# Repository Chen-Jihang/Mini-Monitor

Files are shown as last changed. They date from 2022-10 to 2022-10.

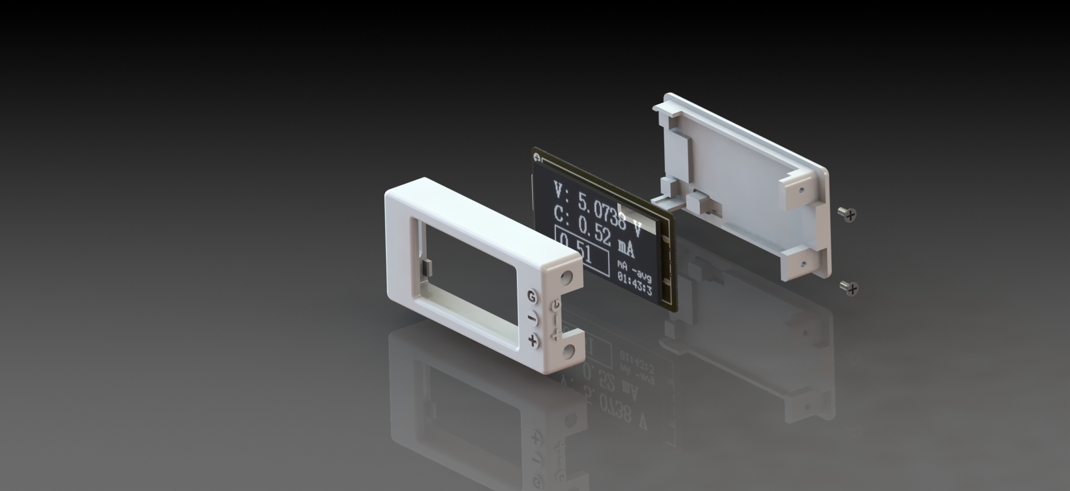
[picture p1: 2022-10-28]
04_Images/rendergraph/GEN_8.JPG

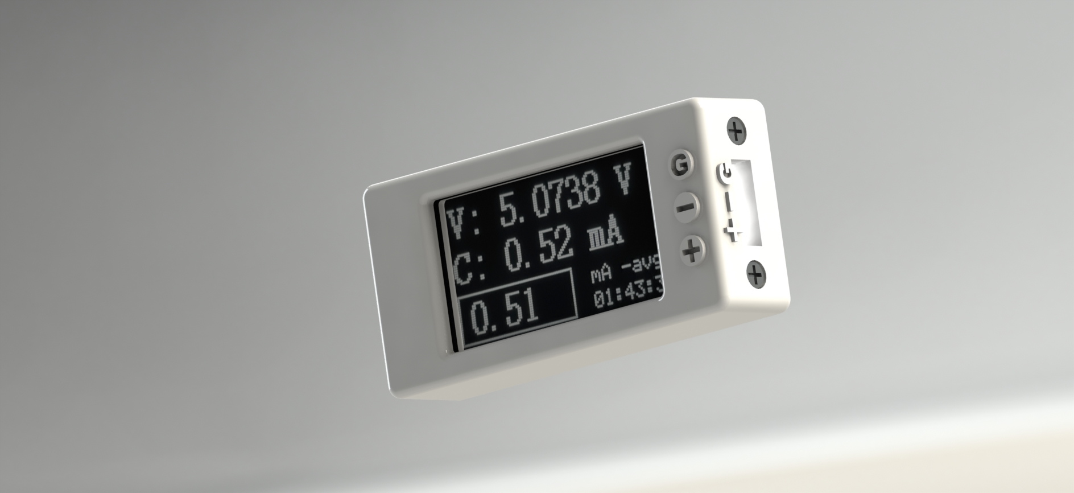
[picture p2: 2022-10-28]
04_Images/rendergraph/GEN_4.JPG

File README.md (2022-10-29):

# Mini-Monitor

> **视频演示**：[【自制一个迷你电流表】](https://www.bilibili.com/video/BV1RD4y1r7Lr/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)
>

## 功能特性
* 电流量程：-655.36mA ~ +655.36mA  
* 电流分辨率：0.02mA  
* 电压量程：0~36V  
* 电压分辨率：1.25mV  
* ADC精度：16-bit  
* 增益误差：0.1% (Max)  
* 输入失调电压：10μV (Max)  
* 供电：5V USB-C  
* 尺寸：48.0*22.4*11.0mm (LWH)  
* 工作温度：-40°C ~ 85°C  
* 主要功能：测电流、电压、计算平均电流  
* 其他优点：体积小巧、操作简单、精度较高
>

> 注：至于为何不设计成更大的量程，因为对于INA226而言，更大的量程意味着降低分辨率。该项目设计的初衷是测量Cat.1模组低功耗，655.36mA对应0.02的分辨率，精度基本满足。调整采样电阻和芯片寄存器值，可改变电流量程和分辨率，下文会有介绍。
> 

## MCU选型
> MCU选用STM32F401CCU6，虽然性能有些过剩，但这个型号是权衡多个因素的结果：  
* 需要支持USB device，设计之初打算再做一个上位机软件，可通过USB在电脑上实时显示曲线图。但后来因为时间原因，这个功能搁置了，直接OLED显示效果也不错。  
* 需要QFN封装，因为 "Mini" 是该产品的特点之一，所以PCB要尽可能设计的小巧，所以QFN是比较合适的封装，QFP封装略显过大。  
* 需要开发方便，ST的芯片工具和资料相对完善。  
* 需要价格适中，考虑过小批量，所以价格因素必须考虑，而当时正处于进口芯片疯狂涨到天价时期，综合比较下来发现芯片价格与性能不完全成正比，与市场需求也有关系。最后选择了STM32F401CCU6，当时拿样价格是 ¥16.8，现在价格肯定有变化。
>

## ADC选型
> 电流测量芯片选用INA226，16-bit，量程和分辨率均可编程。
> 

## INA226的采样电阻取值
> INA226的 Shunt voltage 输入范围是 –81.9175mV~81.92mV；根据所测最大电流可以计算出最大的shunt resistor值，shunt resistor电阻越大，测小电流时误差越小，但是shunt resistor越大，在shunt resistor上的功率损耗也越大，所以需要根据情况折中选择。
> 
> `这里我们选择阻值R100，即0.1欧。` 
> 

## INA226的Calibration Register寄存器取值计算
> 写入 Calibration Register 的值需要根据实际电路中 采样电阻的阻值 和 电流分辨率 来设置，CAL 就是需要写入 Calibration Register 寄存器的值。
> Currnet_LSB 是电流分辨率，这里我们取 0.02mA。
> R_SHUNT 是采样电阻，前面我们取0.1欧。
> 
> `所以 CAL = 0.00512 / (Current_LSB*R_SHUNT)*1000 = 0.00512 / (0.02*0.1)*1000 = 2560`
> 

## INA226的电流量程计算
> 因为INA226的 Shunt voltage input range 最大为 81.92mV，而前面我们采样电阻取值0.1欧，所以在该前提下，最大检测电流为：
> 
> 81.92 / 0.1 = 819.2mA
> 
> 最后再计算 Maximum Expected Current :
> 
> `Maximum Expected Current = Currnet_LSB * 2^15 = 0.02 * 2*15 = 655.36mA`
> 
> 655.36mA < 819.2mA，满足条件，故前面计算的 Calibration Register 寄存器的值，没有问题。
>

注：关于ADC中LSB和MSB的概念理解，可参考如下文章：  
[ADC的最低有效位（LSB）和最高有效位（MSB）的理解](https://blog.csdn.net/wordwarwordwar/article/details/53208584)  
>

## 后记
> 本项目程序代码目前还比较粗糙，欢迎各位大佬前来优化，如有bug请不吝指正，谢谢^_^。
>

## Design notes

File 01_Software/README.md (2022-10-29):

# 版本说明
## Mini-Monitor__no_lvgl :
> 不带LVGL版本，也是演示视频中运行的程序版本。
> 
## Mini-Monitor__with_lvgl :
> 移植好了LVGL-8.2.0，但没有继续开发界面，感兴趣的朋友可在此基础上进一步优化。
>

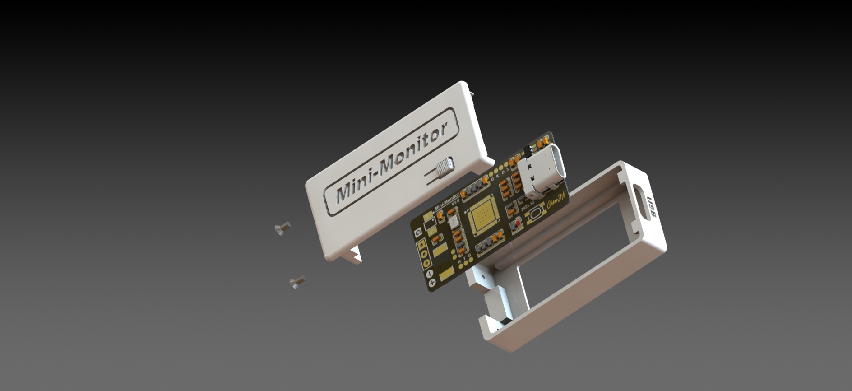
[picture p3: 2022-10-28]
04_Images/rendergraph/GEN_10.JPG

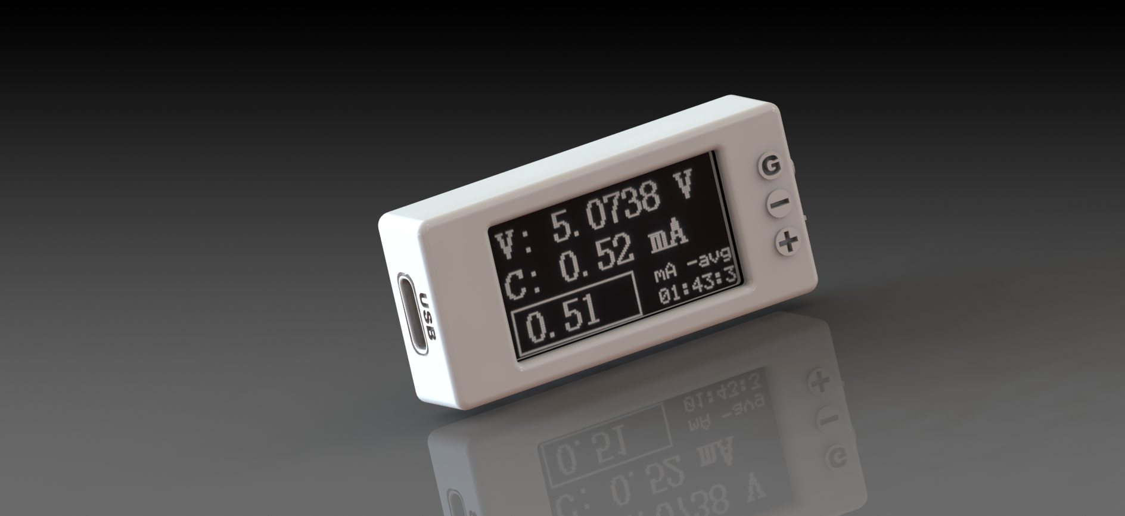
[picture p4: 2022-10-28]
04_Images/rendergraph/GEN_5.JPG

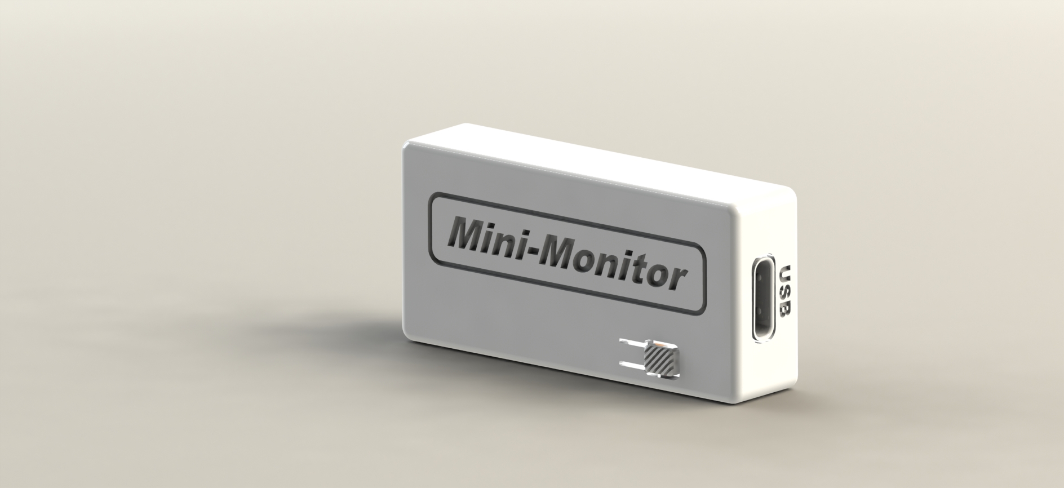
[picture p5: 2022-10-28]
04_Images/rendergraph/GEN_2.JPG

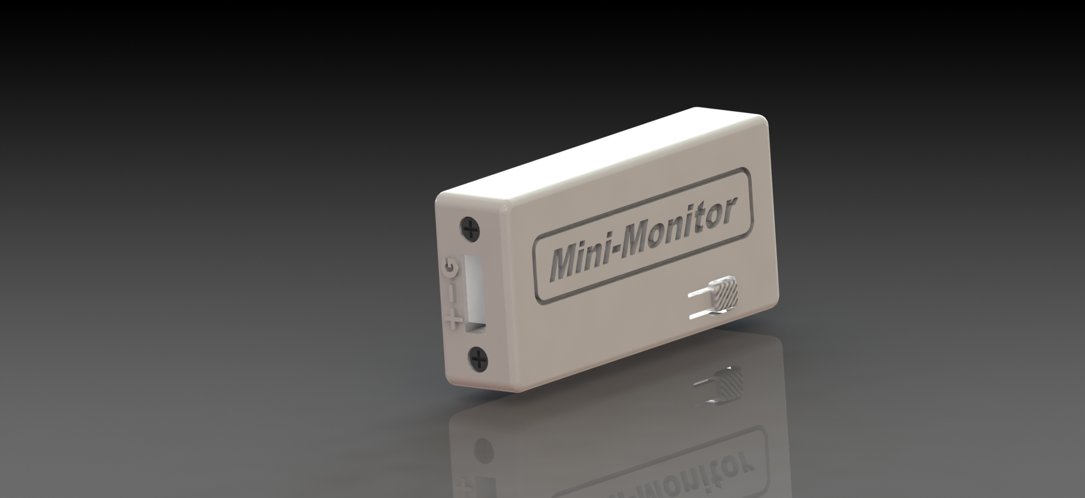
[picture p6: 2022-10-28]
04_Images/rendergraph/GEN_7.JPG

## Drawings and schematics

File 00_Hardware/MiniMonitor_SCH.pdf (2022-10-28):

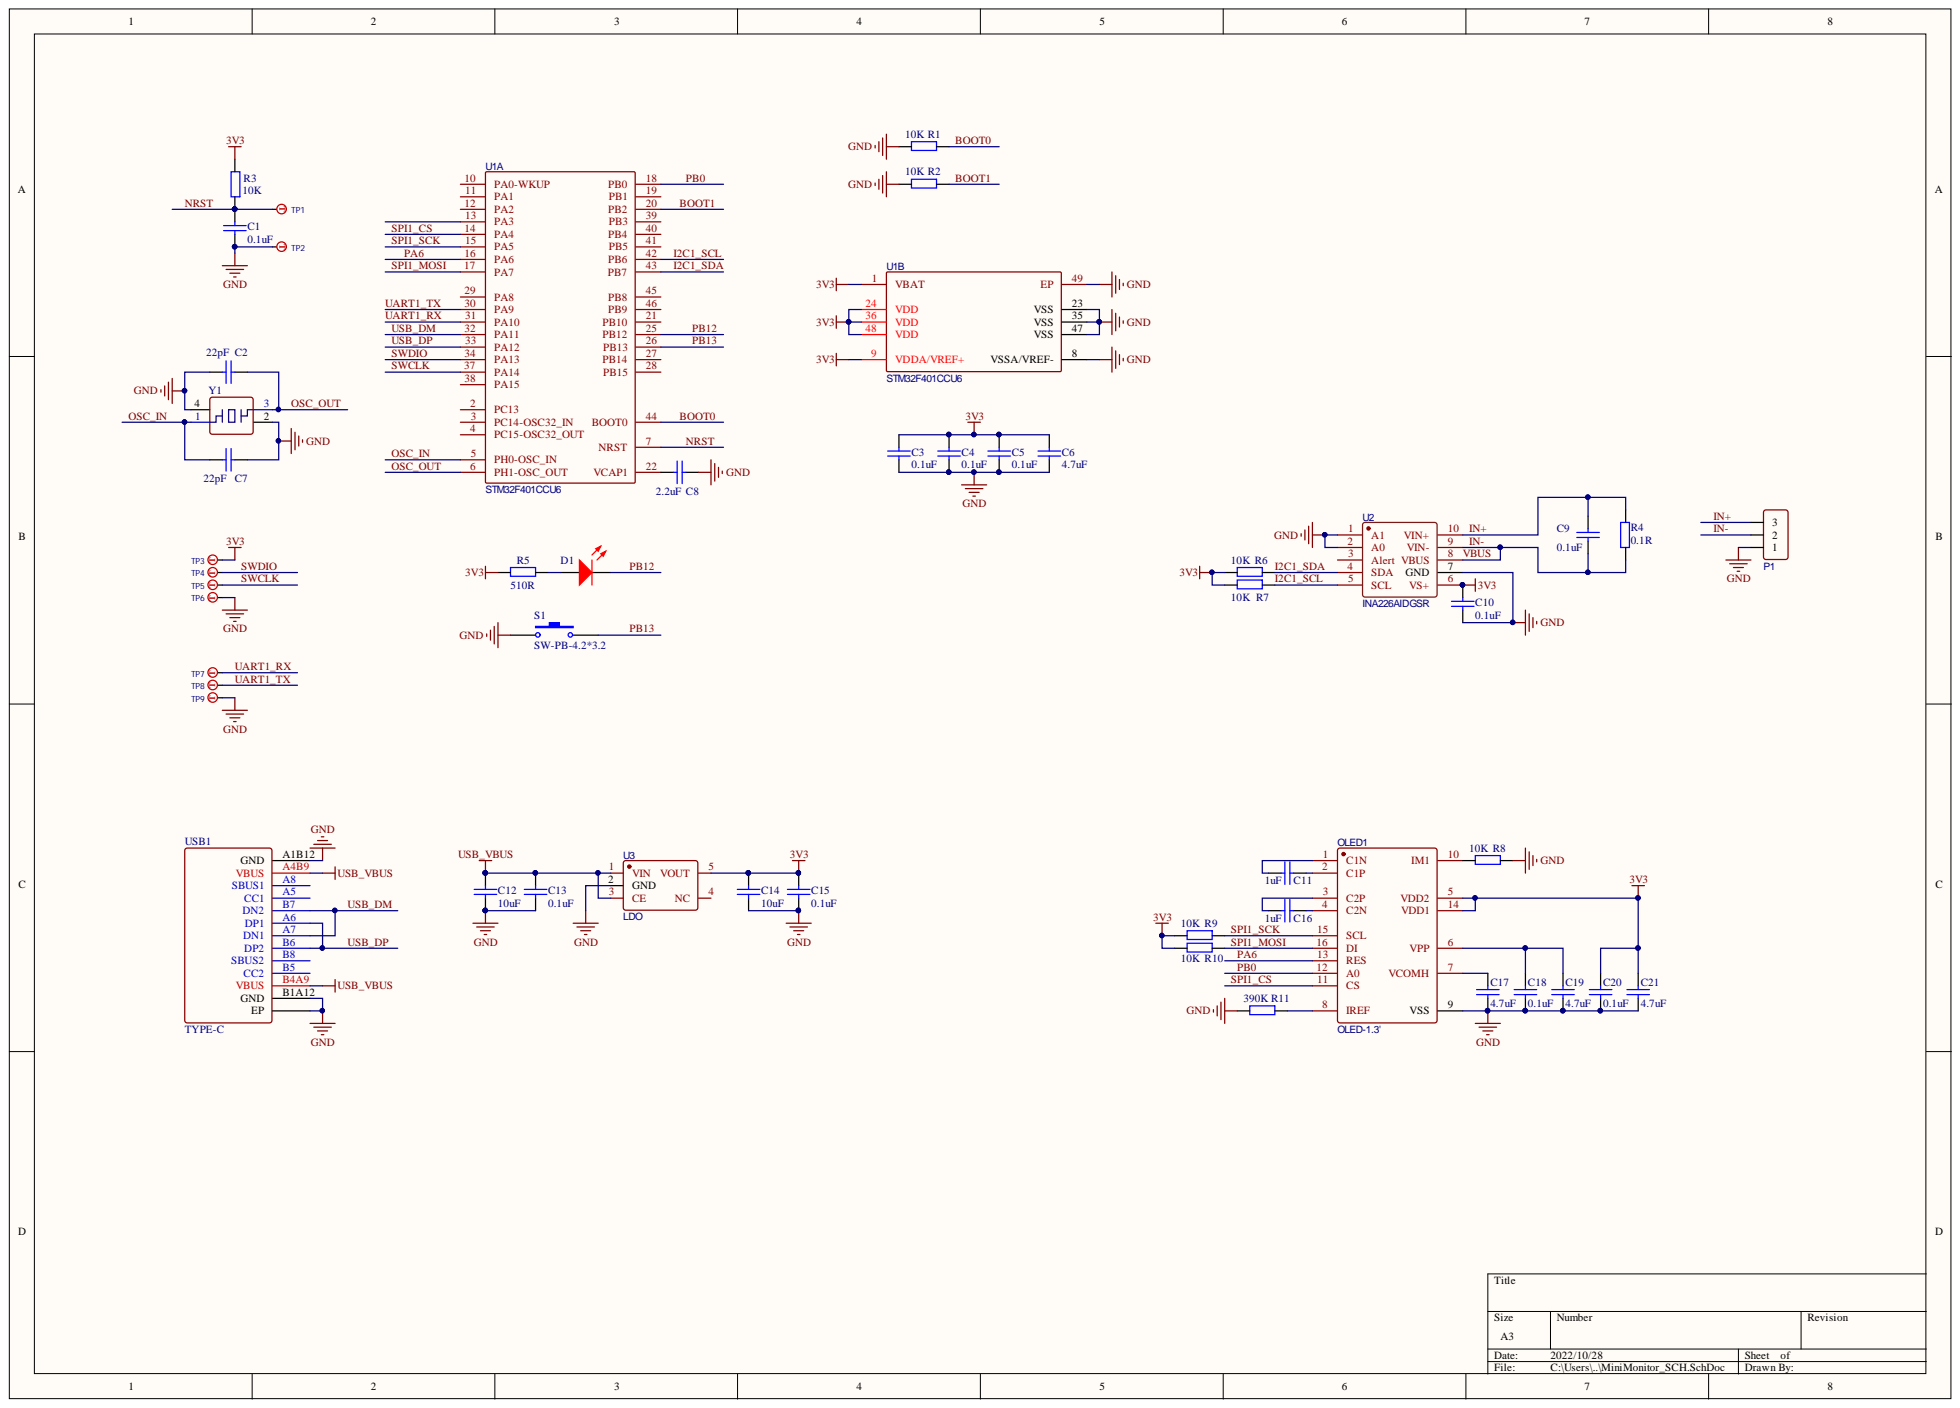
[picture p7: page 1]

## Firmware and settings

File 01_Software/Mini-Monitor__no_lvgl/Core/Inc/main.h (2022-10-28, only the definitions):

#define u8 unsigned char
#define u16 unsigned short
#define u32 unsigned int
#define OLED_CS_Pin					GPIO_PIN_4
#define OLED_CS_GPIO_Port		GPIOA
#define OLED_RST_Pin				GPIO_PIN_6
#define OLED_RST_GPIO_Port	GPIOA
#define OLED_DC_Pin					GPIO_PIN_0
#define OLED_DC_GPIO_Port		GPIOB
#define LED_Pin							GPIO_PIN_12
#define LED_GPIO_Port				GPIOB
#define KEY_Pin							GPIO_PIN_13
#define KEY_GPIO_Port				GPIOB

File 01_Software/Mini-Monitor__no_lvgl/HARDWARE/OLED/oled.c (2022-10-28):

#include "oled.h"
#include "oledfont.h"  	 
#include "main.h"
#include "spi.h"


extern SPI_HandleTypeDef hspi1;
u8 OLED_GRAM[144][8];

			
//发送一个字节
void OLED_WR_Byte(u8 dat,u8 cmd)
{
	if(cmd)
		OLED_DC_Set();
	else
		OLED_DC_Clr();
	OLED_CS_Clr();
	HAL_SPI_Transmit(&hspi1, &dat, 1, 100);
	OLED_DC_Set();
	OLED_CS_Set();
}

//反显函数
void OLED_ColorTurn(u8 i)
{
	if(i==0)
	{
		OLED_WR_Byte(0xA6,OLED_CMD);//正常显示
	}
	if(i==1)
	{
		OLED_WR_Byte(0xA7,OLED_CMD);//反色显示
	}
}

//屏幕旋转180度
void OLED_DisplayTurn(u8 i)
{
	if(i==0)
	{
		OLED_WR_Byte(0xC8,OLED_CMD);//正常显示
		OLED_WR_Byte(0xA1,OLED_CMD);
	}
	if(i==1)
	{
		OLED_WR_Byte(0xC0,OLED_CMD);//反转显示
		OLED_WR_Byte(0xA0,OLED_CMD);
	}
}


//开启OLED显示 
void OLED_DisPlay_On(void)
{
	OLED_WR_Byte(0x8D,OLED_CMD);//电荷泵使能
	OLED_WR_Byte(0x14,OLED_CMD);//开启电荷泵
	OLED_WR_Byte(0xAF,OLED_CMD);//点亮屏幕
}

//关闭OLED显示 
void OLED_DisPlay_Off(void)
{
	OLED_WR_Byte(0x8D,OLED_CMD);//电荷泵使能
	OLED_WR_Byte(0x10,OLED_CMD);//关闭电荷泵
	OLED_WR_Byte(0xAE,OLED_CMD);//关闭屏幕
}

//更新显存到OLED	
void OLED_Refresh(void)
{
	u8 i,n;
	for(i=0;i<8;i++)
	{
	   OLED_WR_Byte(0xb0+i,OLED_CMD); //设置行起始地址
	   OLED_WR_Byte(0x00,OLED_CMD);   //设置低列起始地址
	   OLED_WR_Byte(0x10,OLED_CMD);   //设置高列起始地址
	   for(n=0;n<128;n++)
		 OLED_WR_Byte(OLED_GRAM[n][i],OLED_DATA);
  }
}
//清屏函数
void OLED_Clear(void)
{
	u8 i,n;
	for(i=0;i<8;i++)
	{
		for(n=0;n<128;n++)
		{
			OLED_GRAM[n][i]=0;//清除所有数据
		}
  }
	OLED_Refresh();//更新显示
}

//画点 
//x:0~127
//y:0~63
//t:1 填充 0,清空	
void OLED_DrawPoint(u8 x,u8 y,u8 t)
{
	u8 i,m,n;
	i=y/8;
	m=y%8;
	n=1<<m;
	if(t){OLED_GRAM[x][i]|=n;}
	else
	{
		OLED_GRAM[x][i]=~OLED_GRAM[x][i];
		OLED_GRAM[x][i]|=n;
		OLED_GRAM[x][i]=~OLED_GRAM[x][i];
	}
}

//画线
//x1,y1:起点坐标
//x2,y2:结束坐标
void OLED_DrawLine(u8 x1,u8 y1,u8 x2,u8 y2,u8 mode)
{
	u32 t; 
	int xerr=0,yerr=0,delta_x,delta_y,distance;
	int incx,incy,uRow,uCol;
	delta_x=x2-x1; //计算坐标增量 
	delta_y=y2-y1;
	uRow=x1;//画线起点坐标
	uCol=y1;
	if(delta_x>0)incx=1; //设置单步方向 
	else if (delta_x==0)incx=0;//垂直线 
	else {incx=-1;delta_x=-delta_x;}
	if(delta_y>0)incy=1;
	else if (delta_y==0)incy=0;//水平线 
	else {incy=-1;delta_y=-delta_x;}
	if(delta_x>delta_y)distance=delta_x; //选取基本增量坐标轴 
	else distance=delta_y;
	for(t=0;t<distance+1;t++)
	{
		OLED_DrawPoint(uRow,uCol,mode);//画点
		xerr+=delta_x;
		yerr+=delta_y;
		if(xerr>distance)
		{
			xerr-=distance;
			uRow+=incx;
		}
		if(yerr>distance)
		{
			yerr-=distance;
			uCol+=incy;
		}
	}
}

//画矩形
//x1,y1:起点坐标
//x2,y2:结束坐标
void OLED_DrawRectangle(u8 x1,u8 y1,u8 x2,u8 y2,u8 mode)
{
		OLED_DrawLine(x1,y1,x2,y1,1);
		OLED_DrawLine(x1,y2,x2,y2,1);
		OLED_DrawLine(x1,y1,x1,y2+1,1);
		OLED_DrawLine(x2,y1,x2,y2+1,1);
}

//x,y:圆心坐标
//r:圆的半径
void OLED_DrawCircle(u8 x,u8 y,u8 r)
{
	int a, b,num;
    a = 0;
    b = r;
    while(2 * b * b >= r * r)      
    {
        OLED_DrawPoint(x + a, y - b,1);
        OLED_DrawPoint(x - a, y - b,1);
        OLED_DrawPoint(x - a, y + b,1);
        OLED_DrawPoint(x + a, y + b,1);
 
        OLED_DrawPoint(x + b, y + a,1);
        OLED_DrawPoint(x + b, y - a,1);
        OLED_DrawPoint(x - b, y - a,1);
        OLED_DrawPoint(x - b, y + a,1);
        
        a++;
        num = (a * a + b * b) - r*r;//计算画的点离圆心的距离
        if(num > 0)
        {
            b--;
            a--;
        }
    }
}



//在指定位置显示一个字符,包括部分字符
//x:0~127
//y:0~63
//size1:选择字体 6x8/6x12/8x16/12x24
//mode:0,反色显示;1,正常显示
void OLED_ShowChar(u8 x,u8 y,u8 chr,u8 size1,u8 mode)
{
	u8 i,m,temp,size2,chr1;
	u8 x0=x,y0=y;
	if(size1==8)size2=6;
	else size2=(size1/8+((size1%8)?1:0))*(size1/2);  //得到字体一个字符对应点阵集所占的字节数
	chr1=chr-' ';  //计算偏移后的值
	for(i=0;i<size2;i++)
	{
		if(size1==8)
			  {temp=asc2_0806[chr1][i];} //调用0806字体
		else if(size1==12)
        {temp=asc2_1206[chr1][i];} //调用1206字体
		else if(size1==16)
        {temp=asc2_1608[chr1][i];} //调用1608字体
		else if(size1==20)
        {temp=asc2_2010[chr1][i];} //调用2010字体
		else if(size1==24)
        {temp=asc2_2412[chr1][i];} //调用2412字体
		else return;
		for(m=0;m<8;m++)
		{
			if(temp&0x01)OLED_DrawPoint(x,y,mode);
			else OLED_DrawPoint(x,y,!mode);
			temp>>=1;
			y++;
		}
		x++;
		if((size1!=8)&&((x-x0)==size1/2))
		{x=x0;y0=y0+8;}
		y=y0;
  }
}

void OLED_ShowChar_clean(u8 x,u8 y,u8 chr,u8 size1)
{
	u8 i,m,temp,size2,chr1;
	u8 x0=x,y0=y;
	if(size1==8)size2=6;
	else size2=(size1/8+((size1%8)?1:0))*(size1/2);  //得到字体一个字符对应点阵集所占的字节数
	chr1=chr-' ';  //计算偏移后的值
	for(i=0;i<size2;i++)
	{
		if(size1==8)
			  {temp=asc2_0806[chr1][i];} //调用0806字体
		else if(size1==12)
        {temp=asc2_1206[chr1][i];} //调用1206字体
		else if(size1==16)
        {temp=asc2_1608[chr1][i];} //调用1608字体
		else if(size1==20)
        {temp=asc2_2010[chr1][i];} //调用2010字体
		else if(size1==24)
        {temp=asc2_2412[chr1][i];} //调用2412字体
		else return;
		for(m=0;m<8;m++)
		{
			if(temp&0x01)OLED_DrawPoint(x,y, 0);
			temp>>=1;
			y++;
		}
		x++;
		if((size1!=8)&&((x-x0)==size1/2))
		{x=x0;y0=y0+8;}
		y=y0;
  }
}


//显示字符串
//x,y:起点坐标  
//size1:字体大小 
//*chr:字符串起始地址 
//mode:0,反色显示;1,正常显示
void OLED_ShowString(u8 x,u8 y,u8 *chr,u8 size1,u8 mode)
{
	while((*chr>=' ')&&(*chr<='~'))//判断是不是非法字符!
	{
		OLED_ShowChar(x,y,*chr,size1,mode);
		if(size1==8)x+=6;
		else x+=size1/2;
		chr++;
  }
}

//m^n
u32 OLED_Pow(u8 m,u8 n)
{
	u32 result=1;
	while(n--)
	{
		result*=m;
	}
	return result;
}

//显示数字
//x,y :起点坐标
//num :要显示的数字
//len :数字的位数
//size:字体大小
//mode:0,反色显示;1,正常显示
void OLED_ShowNum(u8 x,u8 y,u32 num,u8 len,u8 size1,u8 mode)
{
	u8 t,temp,m=0;
	if(size1==8)m=2;
	for(t=0;t<len;t++)
	{
		temp=(num/OLED_Pow(10,len-t-1))%10;
		if(temp==0)
		{
			OLED_ShowChar(x+(size1/2+m)*t,y,'0',size1,mode);
		}
		else 
		{
			OLED_ShowChar(x+(size1/2+m)*t,y,temp+'0',size1,mode);
		}
  }
}

//显示汉字
//x,y:起点坐标
//num:汉字对应的序号
//mode:0,反色显示;1,正常显示
void OLED_ShowChinese(u8 x,u8 y,u8 num,u8 size1,u8 mode)
{
	u8 m,temp;
	u8 x0=x,y0=y;
	u32 i,size3=(size1/8+((size1%8)?1:0))*size1;  //得到字体一个字符对应点阵集所占的字节数
	for(i=0;i<size3;i++)
	{
		if(size1==16)
			{temp=Hzk1[num][i];}//调用16*16字体
		else if(size1==24)
			{temp=Hzk2[num][i];}//调用24*24字体
		else if(size1==32)       
			{temp=Hzk3[num][i];}//调用32*32字体
		else if(size1==64)
			{temp=Hzk4[num][i];}//调用64*64字体
		else return;
		for(m=0;m<8;m++)
		{
			if(temp&0x01)OLED_DrawPoint(x,y,mode);
			else OLED_DrawPoint(x,y,!mode);
			temp>>=1;
			y++;
		}
		x++;
		if((x-x0)==size1)
		{x=x0;y0=y0+8;}
		y=y0;
	}
}

//num 显示汉字的个数
//space 每一遍显示的间隔
//mode:0,反色显示;1,正常显示
void OLED_ScrollDisplay(u8 num,u8 space,u8 mode)
{
	u8 i,n,t=0,m=0,r;
	while(1)
	{
		if(m==0)
		{
	    	OLED_ShowChinese(128,24,t,16,mode); //写入一个汉字保存在OLED_GRAM[][]数组中
			t++;
		}
		if(t==num)
		{
			for(r=0;r<16*space;r++)      //显示间隔
			{
				for(i=1;i<144;i++)
				{
					for(n=0;n<8;n++)
					{
						OLED_GRAM[i-1][n]=OLED_GRAM[i][n];
					}
				}
				OLED_Refresh();
			}
        	t=0;
      	}
		m++;
		if(m==16){m=0;}
		for(i=1;i<144;i++)   //实现左移
		{
			for(n=0;n<8;n++)
			{
				OLED_GRAM[i-1][n]=OLED_GRAM[i][n];
			}
		}
		OLED_Refresh();
	}
}
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

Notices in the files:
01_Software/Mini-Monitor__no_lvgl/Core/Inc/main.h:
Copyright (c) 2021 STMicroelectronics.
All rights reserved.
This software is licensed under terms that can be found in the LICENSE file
